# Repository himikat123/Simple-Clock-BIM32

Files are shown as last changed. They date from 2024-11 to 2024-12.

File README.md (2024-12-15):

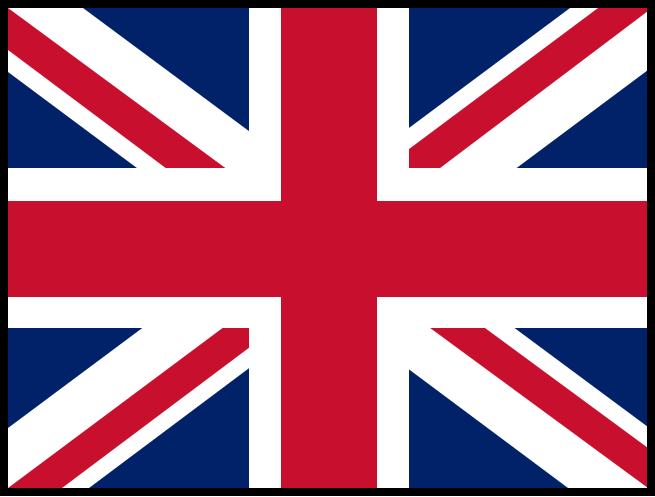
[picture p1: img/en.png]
Read this in english

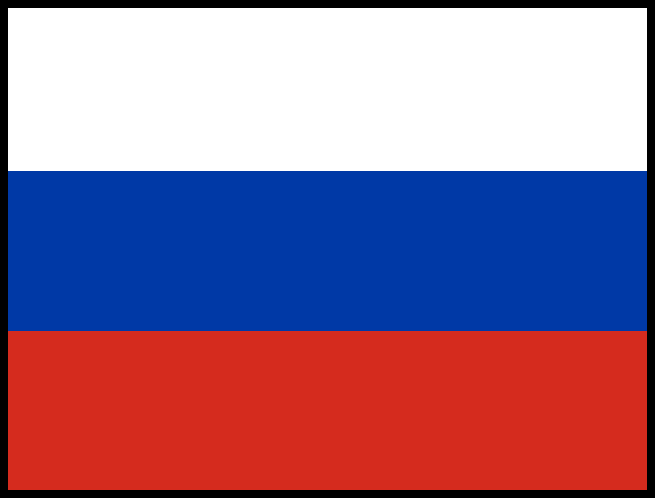
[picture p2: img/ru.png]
Читать на русском
 

# Simple Clock BIM32
## Clock based on ESP32 and TM1637 or MAX7219 Display

<p align="center">simple clock bim32</p>

Simple clock, you can connect 1 or 2 identical or different displays. Each display can have 4, 6, or 8 digits. In this article I will show this clock in its simplest version, i.e. ESP32, 1 display (8 digits) and a case. 
I will also talk about the additional features of this clock as well. Thanks to the large number of possibilities and settings, everyone can build a suitable clock for himself, with a set of individual functions.

### Brief list of clock features:

* Display time (hours, minutes, seconds, milliseconds), date, month, and year
* Connects to a 2.4 GHz home WiFi network
* Synchronizes the time with an NTP server
* Displays current weather (temperature/pressure/humidity)
* Displays indoor temperature, humidity, CO2 levels, and air quality
* Controls home climate devices (humidifier, dehumidifier, heater, cooler, air purifier)
* Sends/receives data to/from the Thingspeak service
* Sends data to the narodmon service
* Supports up to 2 wireless temperature/pressure/humidity/CO2/light/voltage/current/power/energy consumption sensors
* Supports wired sensors for temperature/pressure/humidity/light/air quality
* Auto adjusts screen brightness (based on a light sensor, time, or sunrise/sunset)
* Option to connect a second display
* Speaking clock function
* Alarm clock that plays MP3 files
* Sound notification when temperature, humidity, CO2, or air quality exceeds comfort limits
* Highly flexible settings via web interface

## Display Connection Diagram
To start and operate the clock, it is enough to connect the **display** to the **ESP32**. Connecting all other modules is optional.

Instead of conventional schematics, I’ve provided semi-drawings/semi-photos for clarity, even for beginners and non-professionals. Professionals, please don't be upset—proper schematics will be provided too.

You can use a ready-made display on a specialized chip TM1637 (4 or 6 digits), or on MAX7219 (4 to 8 digits). These displays are very common and cheap, it is not difficult to buy one. The diagram below shows how to connect the display. I have shown both supported displays, but only one needs to be connected.

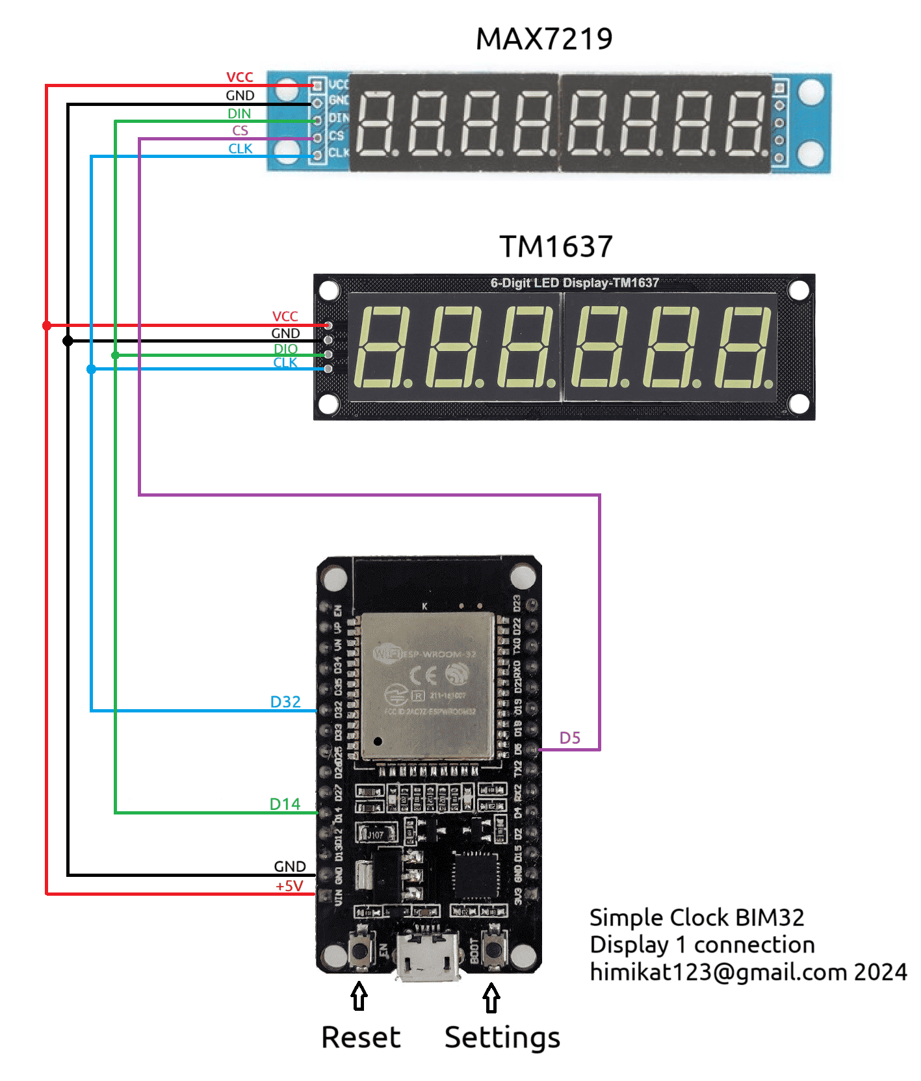
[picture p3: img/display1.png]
simple clock BIM32 display1 wiring diagramm


Additionally, a second display can be connected using the following diagram:

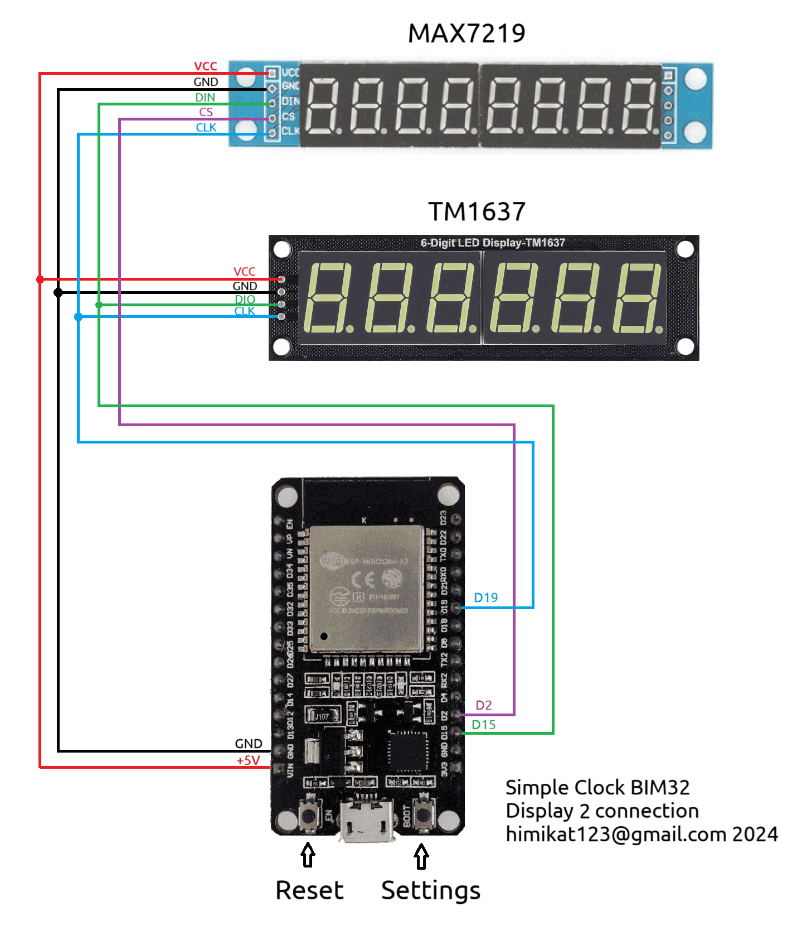
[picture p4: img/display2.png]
simple clock BIM32 display2 wiring diagramm


If you need to have a button (or buttons) handy to turn the display(s) on/off, they can be connected as shown in the diagram.

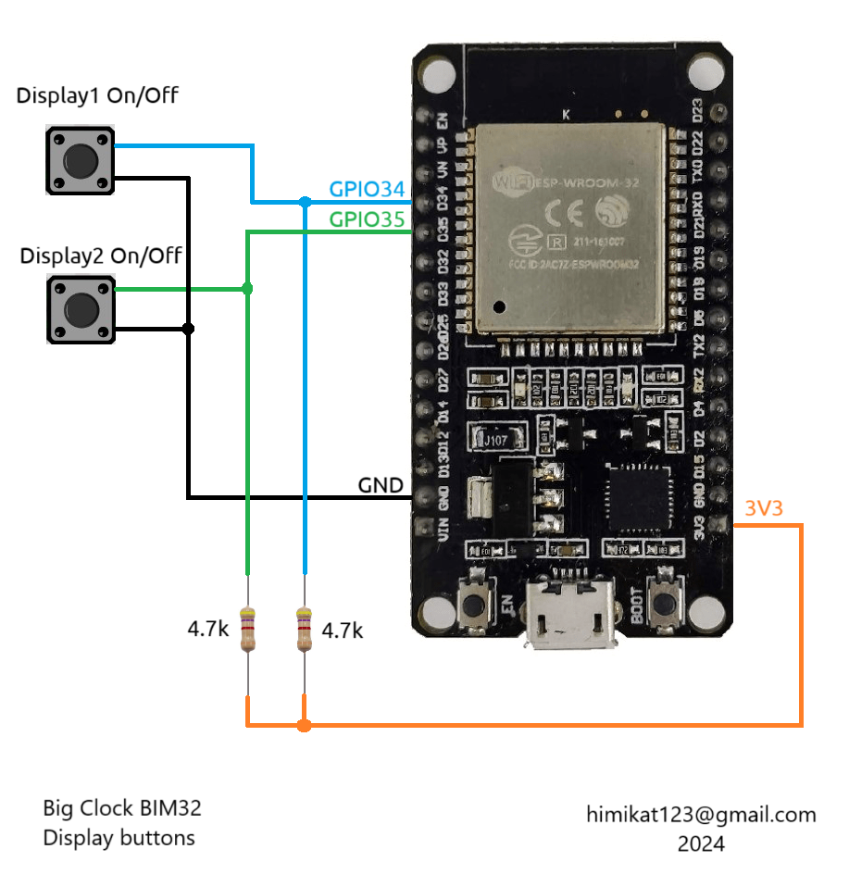
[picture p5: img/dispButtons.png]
simple clock BIM32 display buttons


## Connecting Wired Sensors 
The **clock** can connect to wired sensors for temperature, humidity, pressure, air quality, and light level. Supported sensors include:

* BME280
* BME680
* BMP180
* SHT21
* DHT22
* DS18B20
* MAX44009
* BH1750
* Photoresistor

You can connect one, several, or all of the sensors from this list. It's also recommended to install the DS3231 real-time clock chip, though it is not required. The connection diagram is as follows:

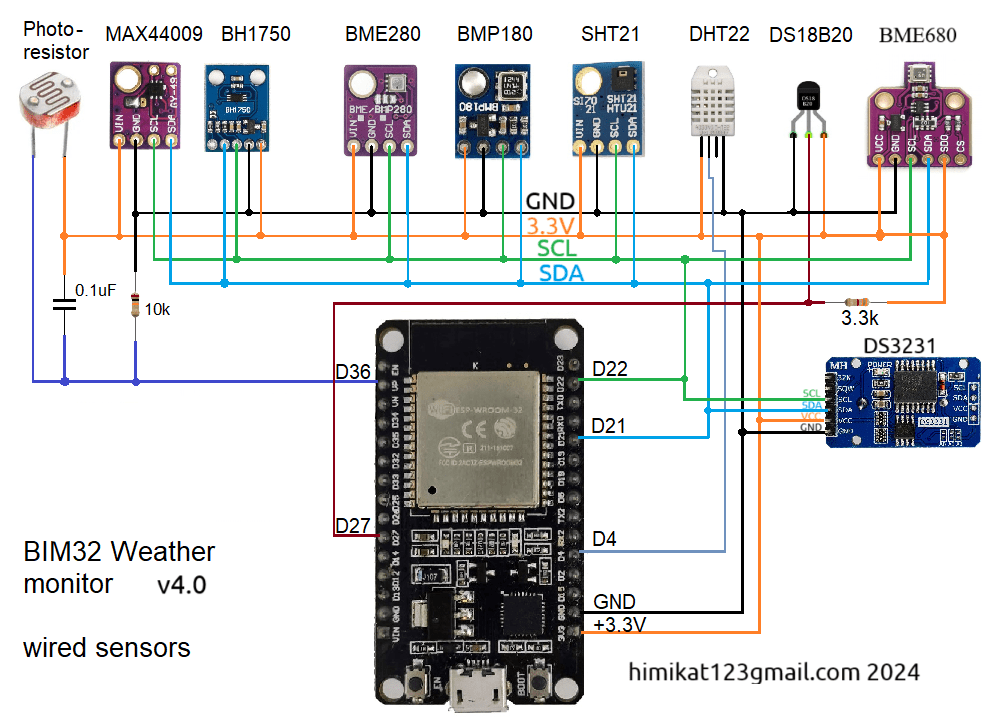
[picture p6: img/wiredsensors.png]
simple clock BIM32 wired sensors


## Wireless Sensor Connection Diagram 
The **clock** can also be connected to **[wireless sensors](https://github.com/himikat123/Radio-sensor)** by adding the **HC-12** radio module, following the diagram below.

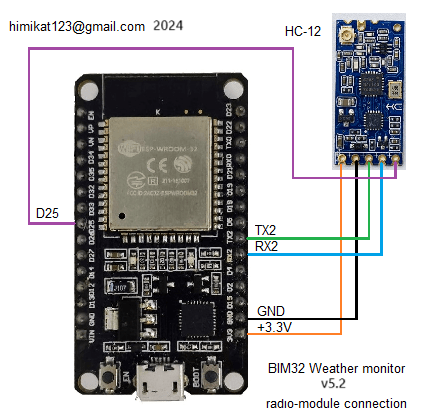
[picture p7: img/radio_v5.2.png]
simple clock BIM32 radio channel


## Home Climate Control Device Connection Diagram 
To control the climate in your home, you can connect a humidifier and dehumidifier, as well as a heater, cooler (fan or air conditioner), and air purifier. I can't provide a connection diagram for these devices because it depends on how the control is implemented in each specific device (remote control, buttons, voltage). However, I will outline on which pins of the **PCF8574** the logic high signals will appear when each device needs to be turned on.

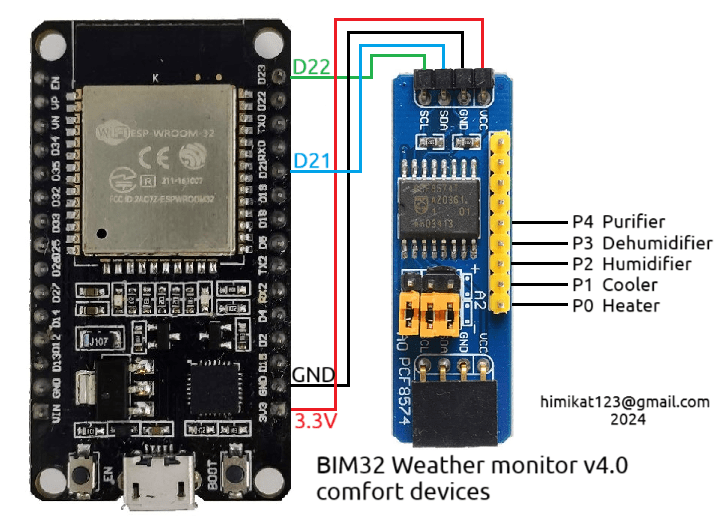
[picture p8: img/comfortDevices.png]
simple clock BIM32 humidifier dehumidifier heater cooler


## Sound Module Connection Diagram 
To enable the alarm and speaking clock sounds, the **DF-Player mini** MP3 player module is used, with the connection diagram provided below. You will need to copy all contents from the **SDcard folder** onto a **micro-SD card**, formatted in **FAT32**. If sound is not required, connect the ESP32's GPIO18 pin to ground.

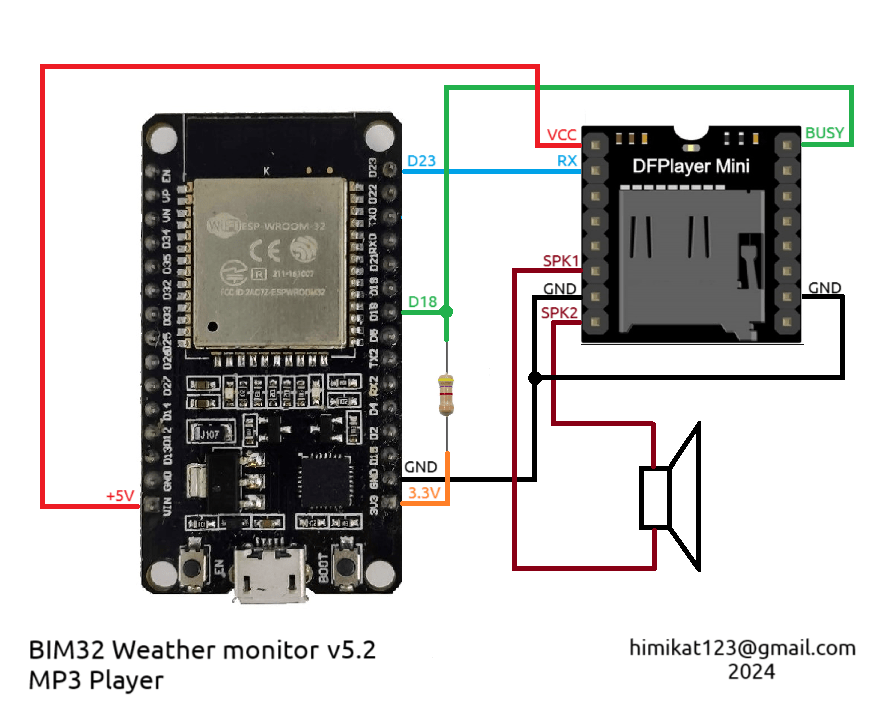
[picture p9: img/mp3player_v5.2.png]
simple clock BIM32 MP3-player


During use, an unpleasant issue with the MP3 player module was discovered: it produces constant low noise. To eliminate the noise, the resistor needs to be resoldered from position A to position B, as shown in the photo below. This switches the MUTE input of the amplifier to the BUSY output, which produces a logic signal only when sound is playing.

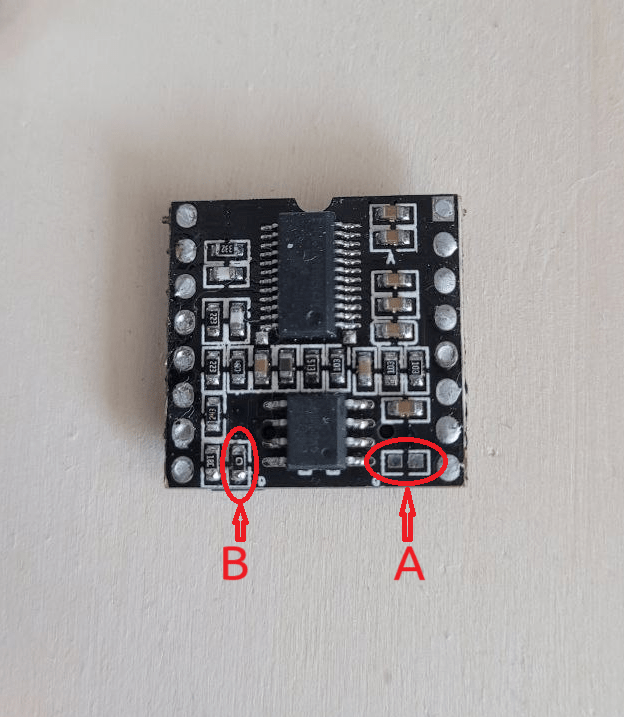
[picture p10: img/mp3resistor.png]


## Clock Schematic

As promised, here's a proper general schematic for general reference. 

```diff
- Please note: if you choose not to install the buttons 
- (to turn the display on/off or disable the alarm), 
- the pull-up resistors for these buttons still need to be installed.
```

The diagram shows all the parts that can make up the clock. But, as I said before, except for the ESP32 module and one of the displays, all other parts do not need to be installed. Light sensor (BH1750, MAX44009 or photoresistor), if you need it, install it in the clock case. But the temperature and humidity sensors should be installed outside the case of the clock, because inside the case the temperature is higher, respectively the humidity is lower. 

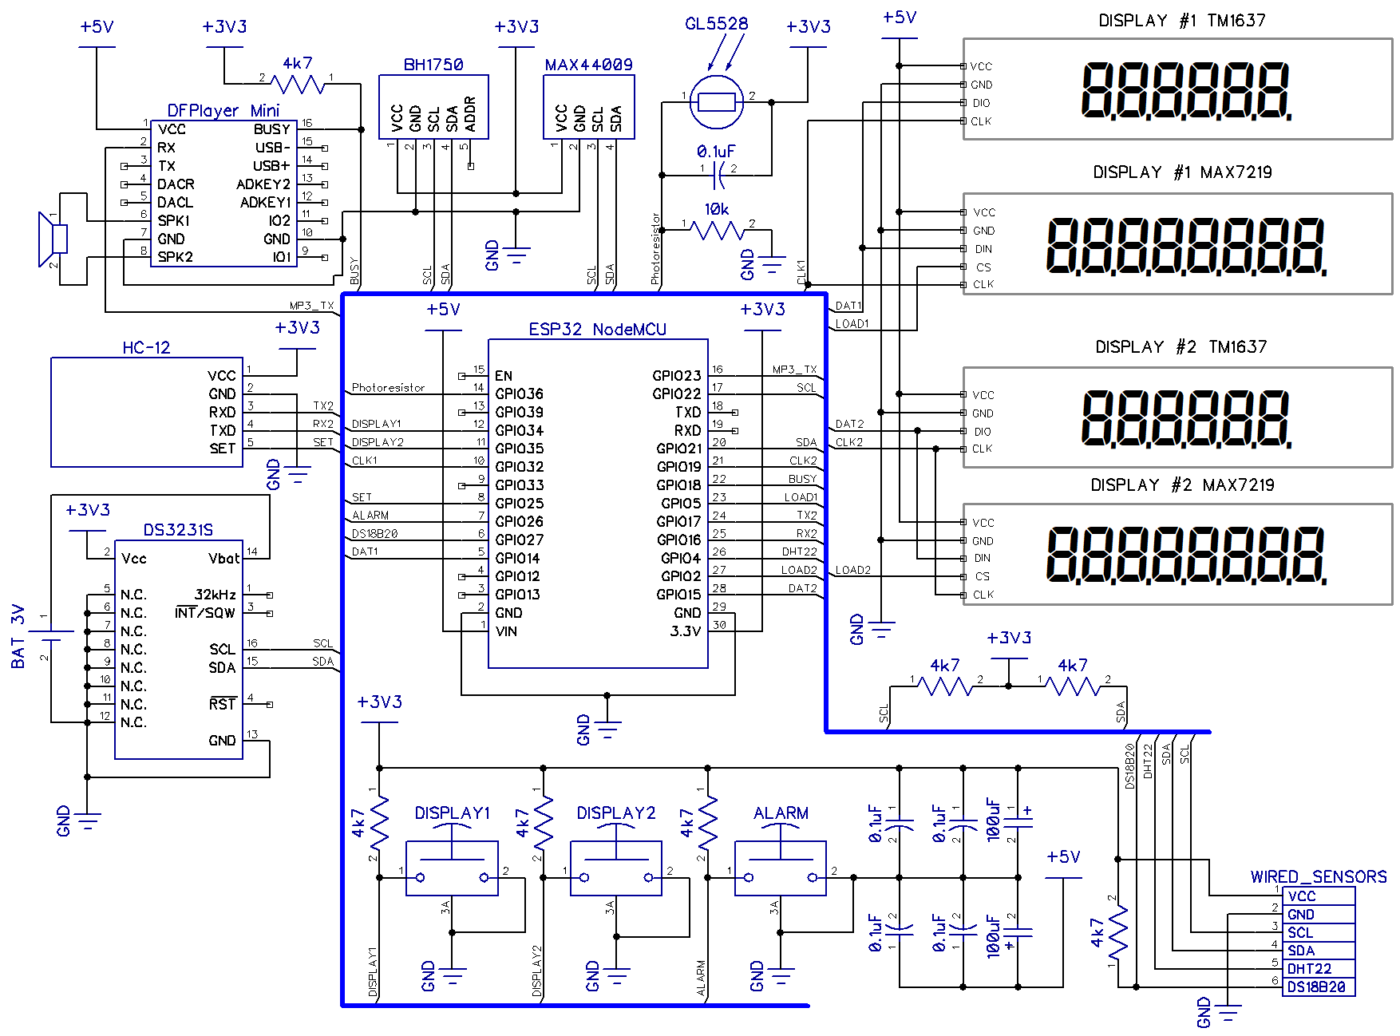
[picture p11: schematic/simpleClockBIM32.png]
simple clock BIM32 schematic diagramm


I didn't make a PCB, I mounted everything by surface mount. Of course, if you need 2 displays and you will use sound module, wired and wireless sensors, buttons, it is better to make a PCB. If someone makes a board, please send me the files and I will add them to the repository.

## Clock Firmware

There is no separate firmware for this clock. The firmware from the [BIM32 weather monitor](https://github.com/himikat123/Weather-monitor-BIM32) is compatible.

To flash the clock firmware, you will need a **micro-USB** cable and a computer:
1. Download [flash_download_tools](https://www.google.ru/search?q=flash_download_tools)
2. Run it and select ESP32 DownloadTool
3. Select the firmware binary files (found in the [bin](https://github.com/himikat123/Weather-monitor-BIM32/tree/master/bin) folder) and addresses as shown in the screenshot, along with the COM port number
4. Press the Start button in the flashing tool and the Settings button on the clock (BOOT button on the ESP32 module). Hold the Settings button until flashing begins.

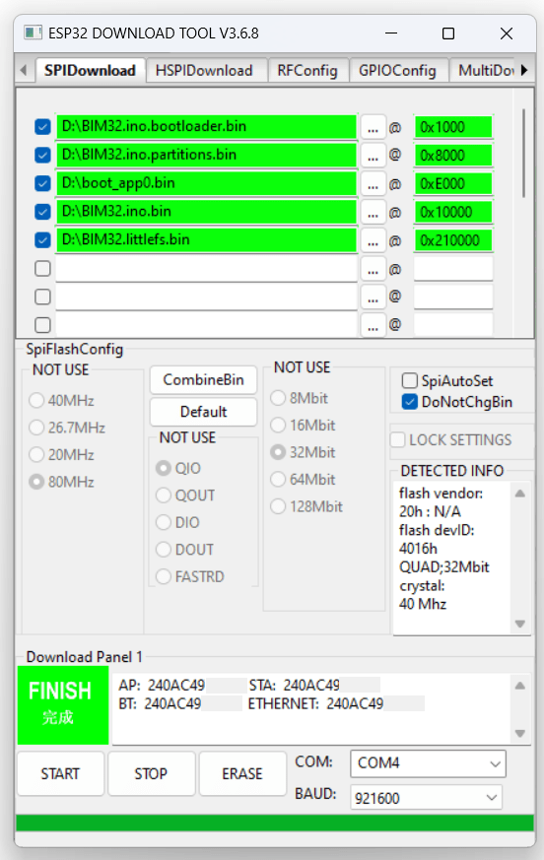
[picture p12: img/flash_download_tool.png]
simple clock BIM32 flashing


After flashing, the **clock** needs to be configured. Unconfigured clock will automatically enable the access point **BIM32** (create a WiFi network) with the default password **1234567890**. Later, to re-enable this network, press and hold the **Settings button** until **"AP"** (short for Access Point) appears on the screen. Connect a laptop or phone to the **BIM32** network, open a browser, and go to **http://192.168.4.1**. Enter the username **"admin"** and the password **"1111"** to access the settings page. It’s recommended to change the default username and password for security purposes.

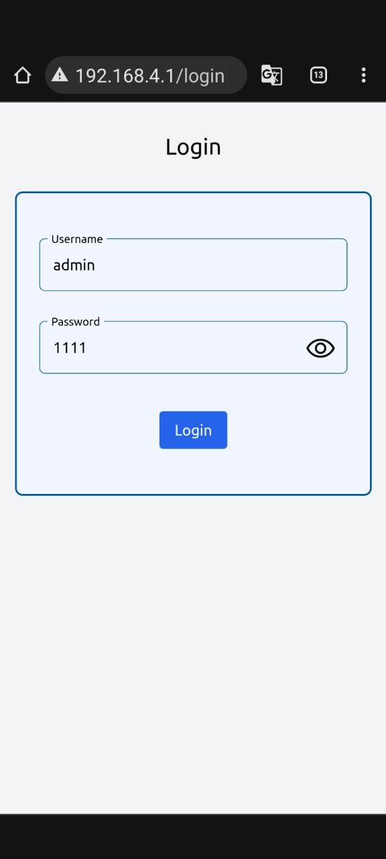
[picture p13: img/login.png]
simple clock BIM32 login


Additionally, once the **clock** is configured and connected to the network, you can access the settings without pressing the Settings button by entering the clock’s **IP address** in a browser. You can find this address in your router or set a static IP in the clock settings.

<hr />

## Settings Demo Page can be viewed <a href="https://himikat123.github.io/Web-Interface-BIM/" target="_blank">here</a>.

## Clock Assembly Photo Instructions 

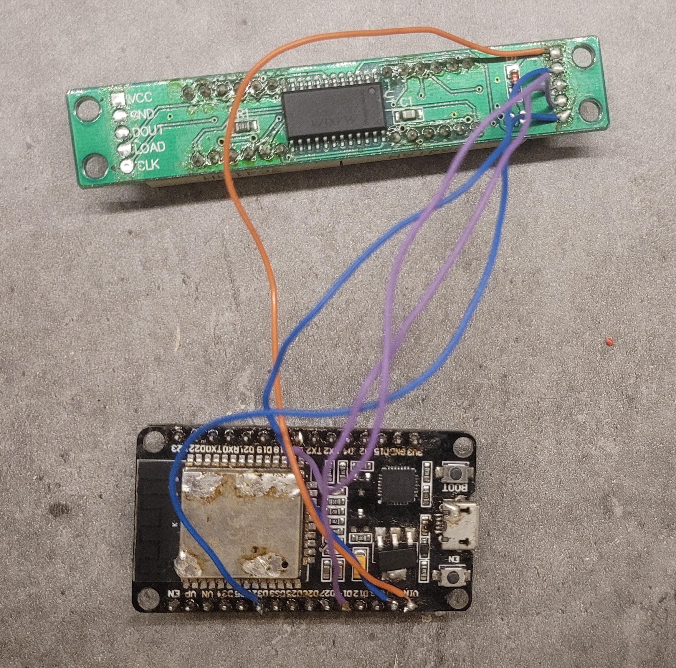
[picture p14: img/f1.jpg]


All three parts of the case (the case itself, the back panel and the buttons) are printed on a 3d printer, you will find the files for 3d printing in the **STL** folder.

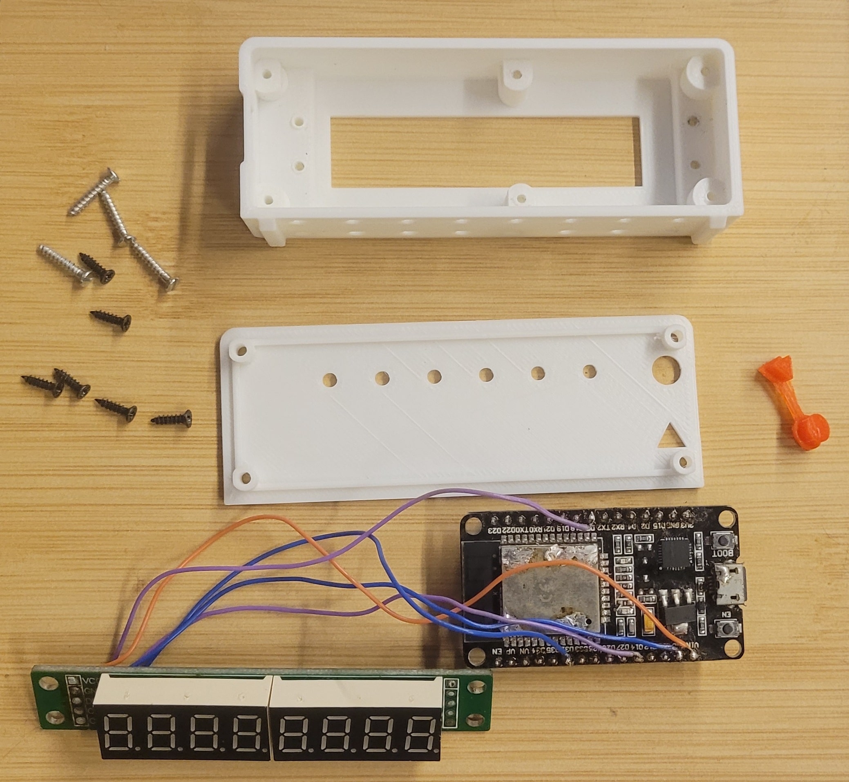
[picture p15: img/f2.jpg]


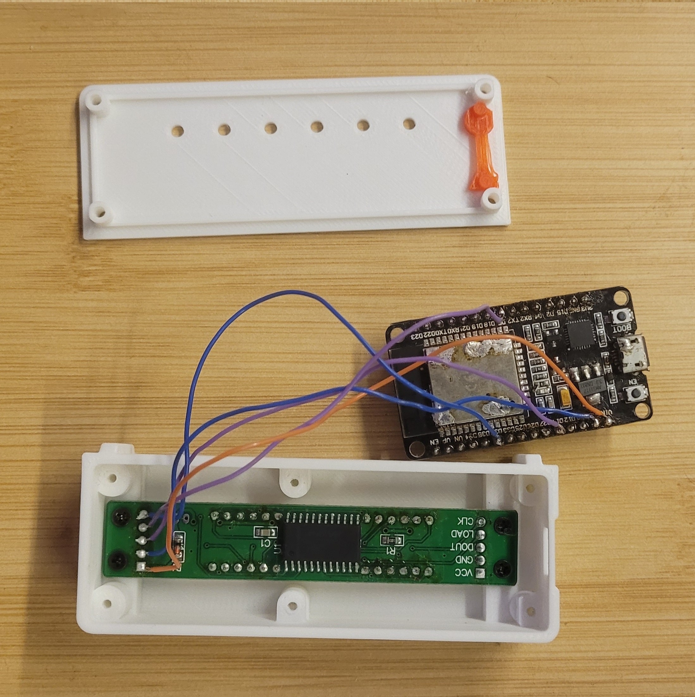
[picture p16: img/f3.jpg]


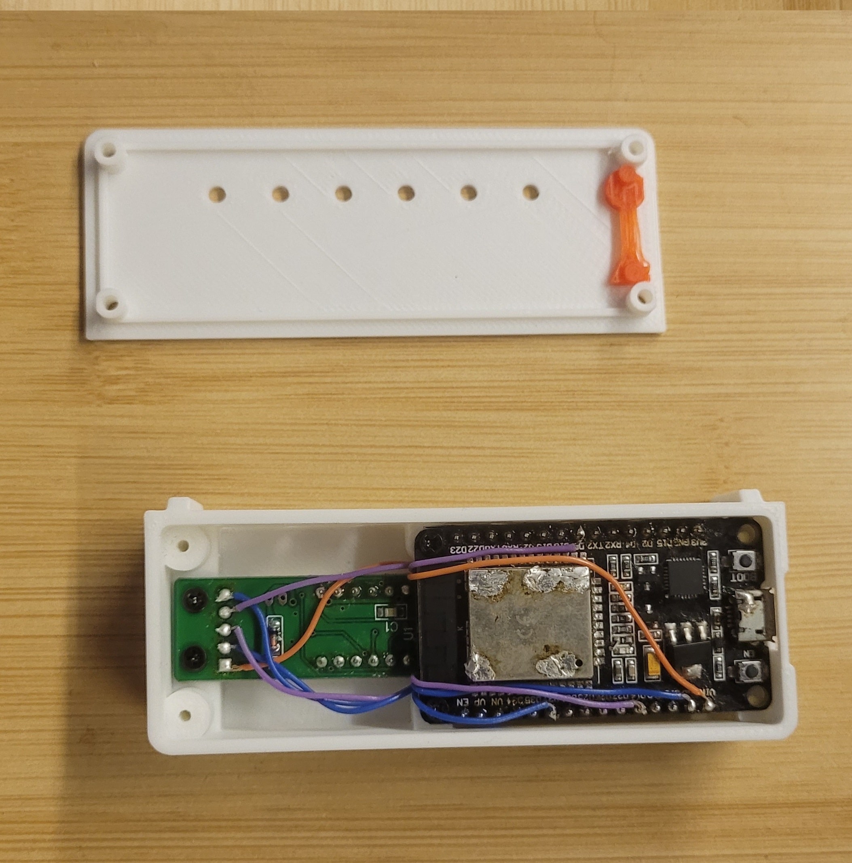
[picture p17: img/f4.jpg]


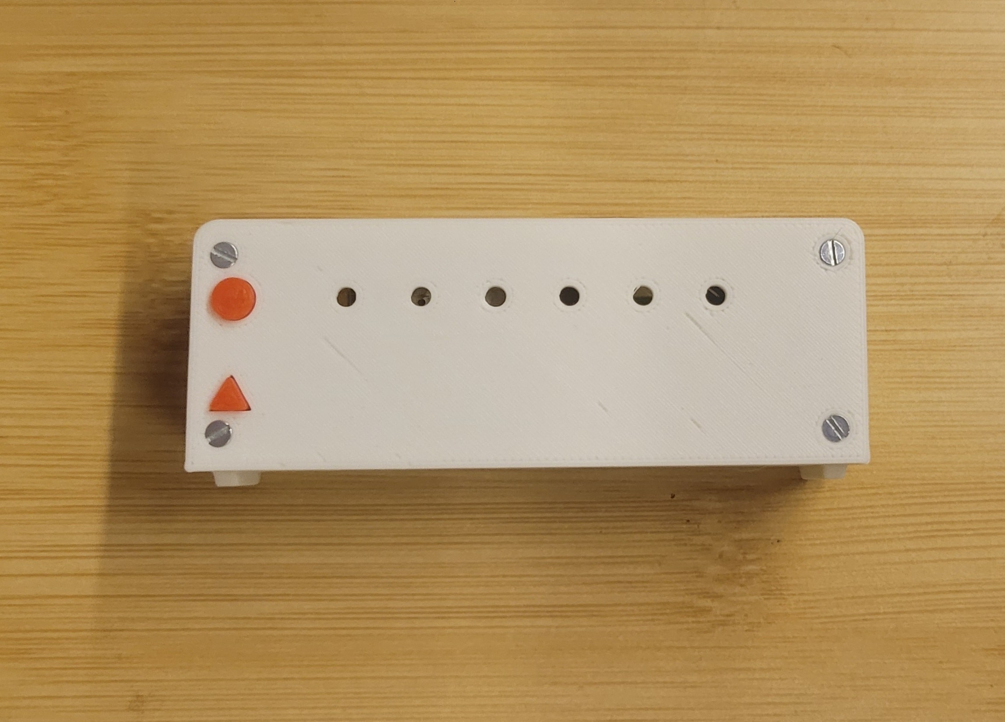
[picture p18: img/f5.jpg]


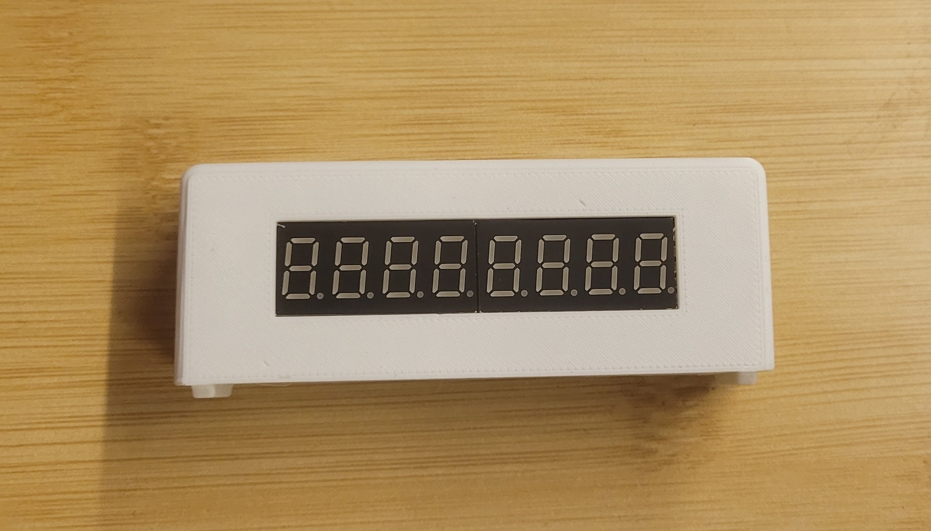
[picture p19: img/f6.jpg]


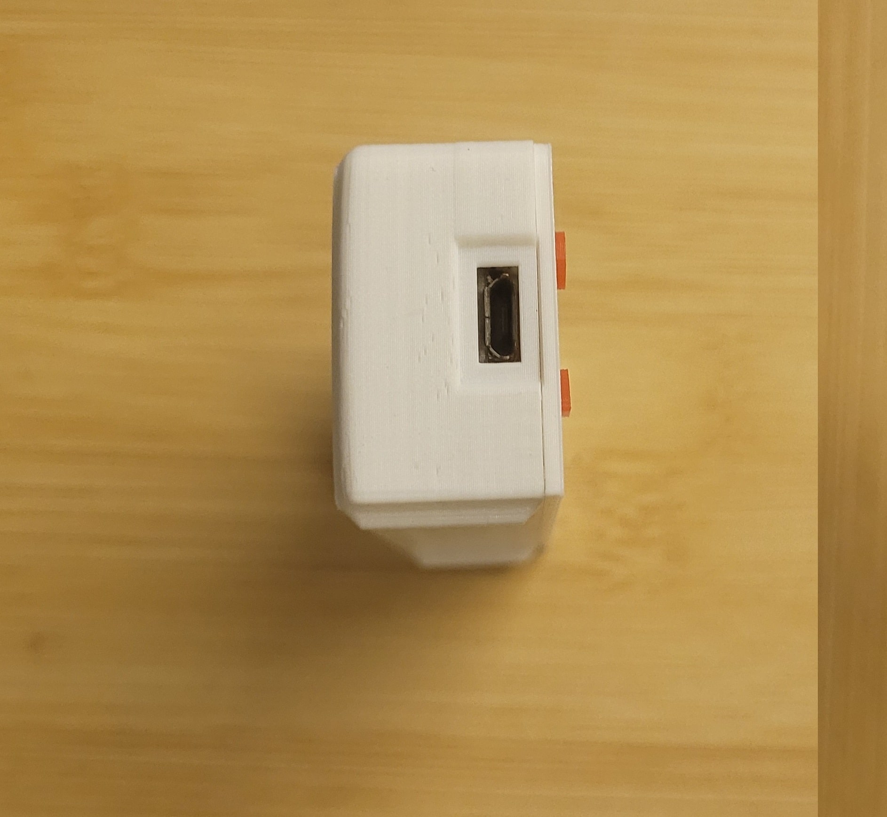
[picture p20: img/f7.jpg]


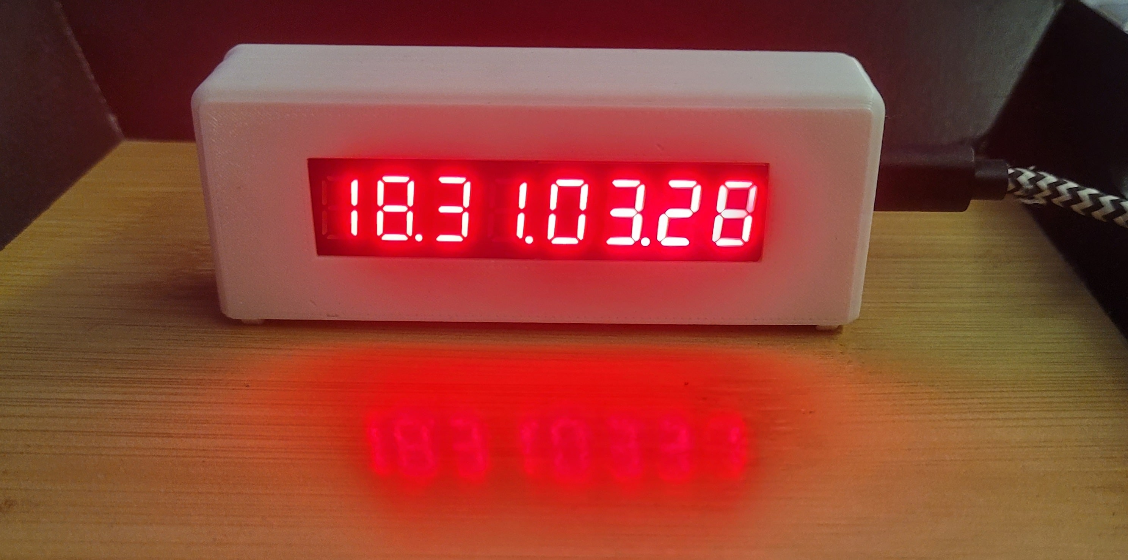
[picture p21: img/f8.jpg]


<hr>

## Do you like the project? Buy me coffee or beer.

<a href="https://www.buymeacoffee.com/himikat123Q">
    Donate
</a>

<a href="https://www.paypal.com/donate/?hosted_button_id=R4QDCRKTC9QA6">
    
</a>

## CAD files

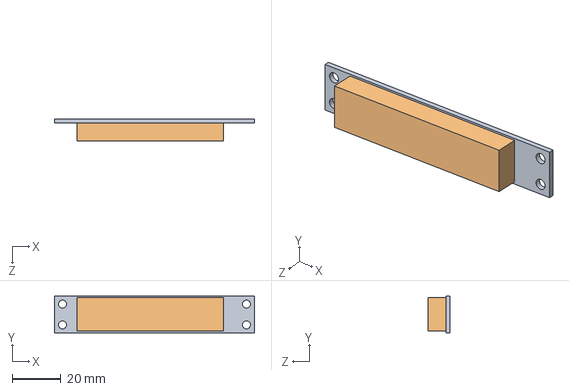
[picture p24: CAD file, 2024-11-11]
Solidworks2023/display 0.36/display.SLDASM
82.4 x 15.2 x 8.90 mm
disp
disp_pcb

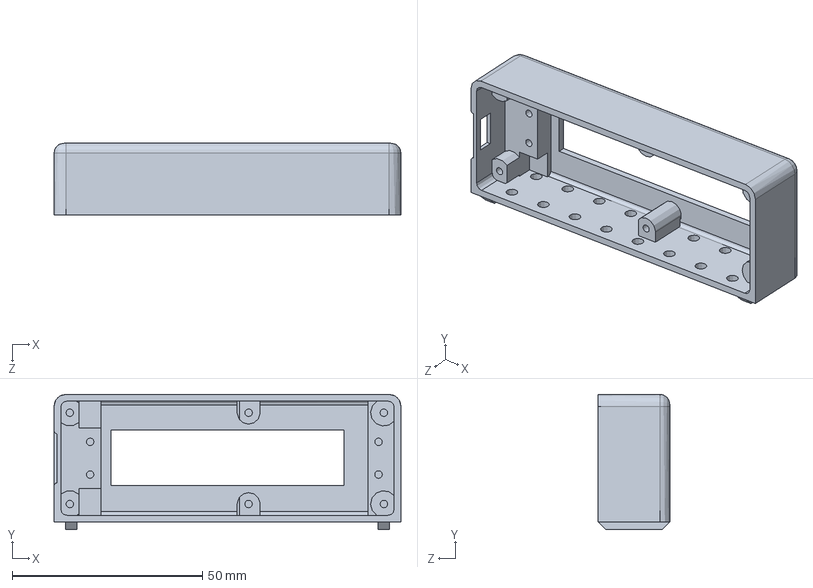
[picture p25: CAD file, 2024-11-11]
Solidworks2023/face.SLDPRT
91.2 x 35.6 x 18.8 mm

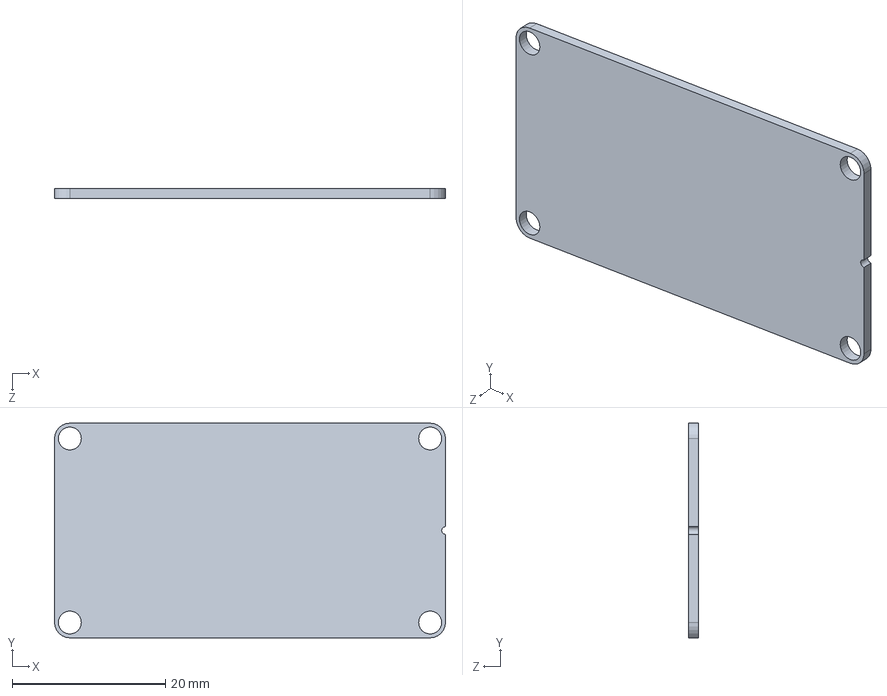
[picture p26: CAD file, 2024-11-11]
Solidworks2023/node mcu/pcb.SLDPRT
51.0 x 28.0 x 1.30 mm

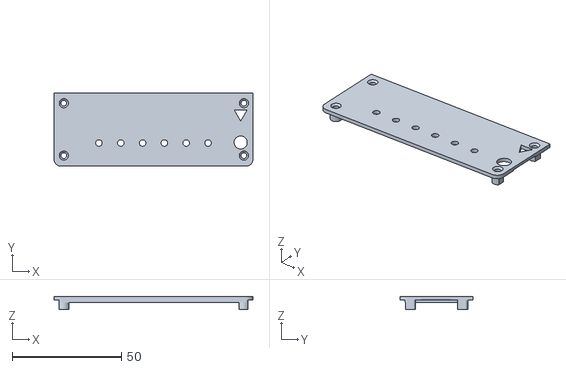
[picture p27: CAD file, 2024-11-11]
STL/cover.STL
91.2 x 33.6 x 6.00

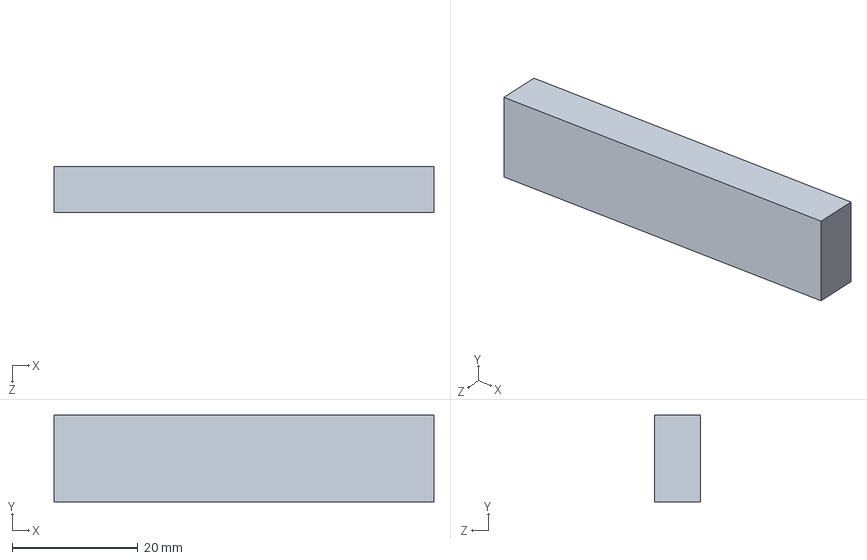
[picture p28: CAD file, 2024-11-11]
Solidworks2023/display 0.36/disp.SLDPRT
60.4 x 13.8 x 7.30 mm

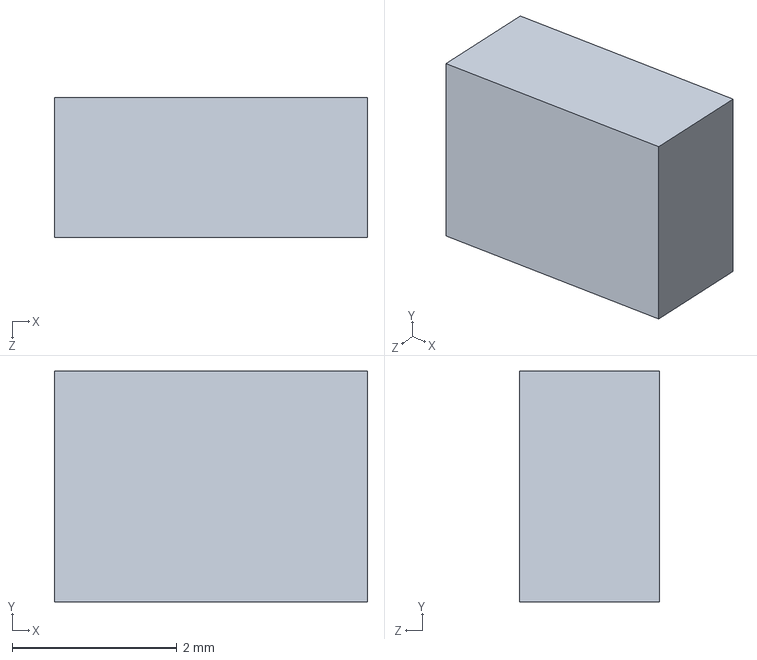
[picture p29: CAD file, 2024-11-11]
Solidworks2023/node mcu/btn1.SLDPRT
3.80 x 2.80 x 1.70 mm

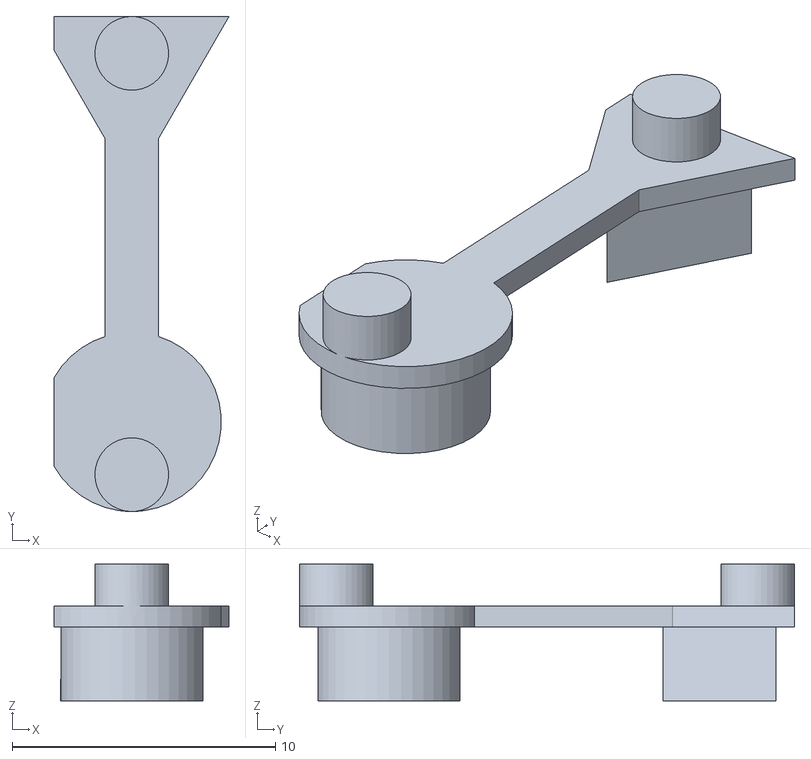
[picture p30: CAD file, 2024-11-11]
STL/buttons.STL
6.65 x 18.8 x 5.20

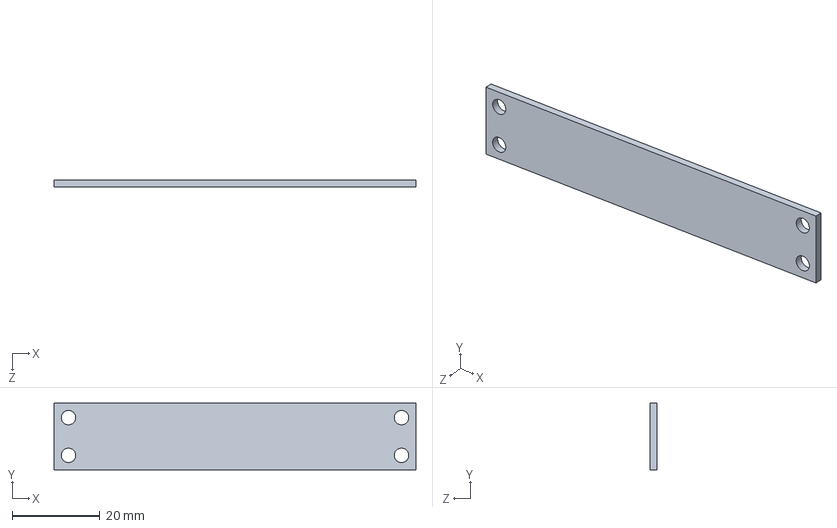
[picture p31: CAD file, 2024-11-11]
Solidworks2023/display 0.36/disp_pcb.SLDPRT
82.4 x 15.2 x 1.60 mm

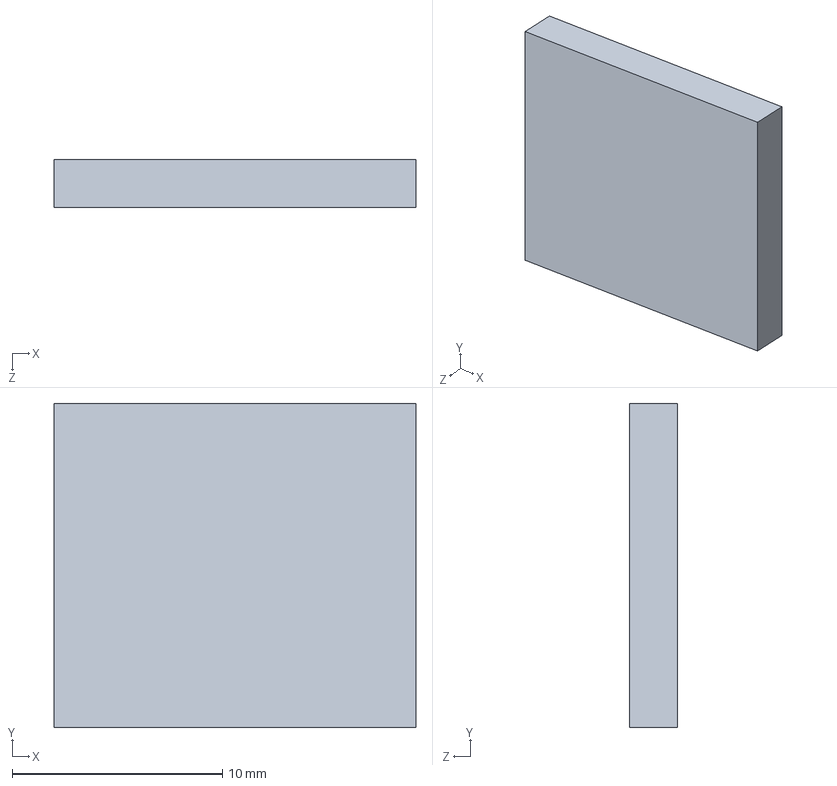
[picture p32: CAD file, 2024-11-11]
Solidworks2023/node mcu/esp2.SLDPRT
17.2 x 15.4 x 2.30 mm

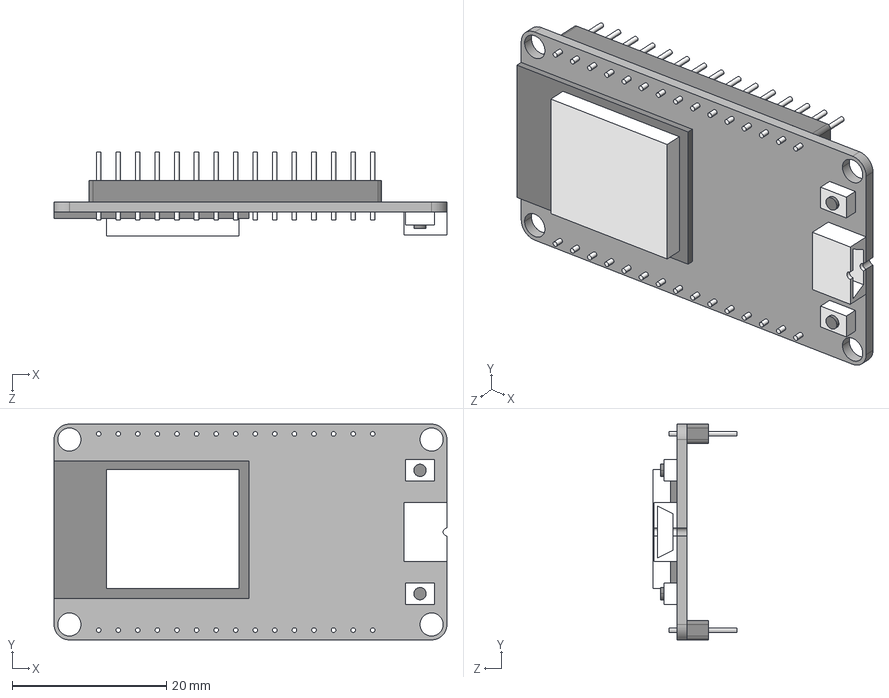
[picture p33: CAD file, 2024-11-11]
Solidworks2023/node mcu/esp32.STEP
51.0 x 28.0 x 10.9 mm
pcb_Standard
esp1_Standard
esp2_Standard
btn1_Standard x 2
btn2_Standard x 2
usb_Standard
dip_Standard x 2
pin_Standard x 2

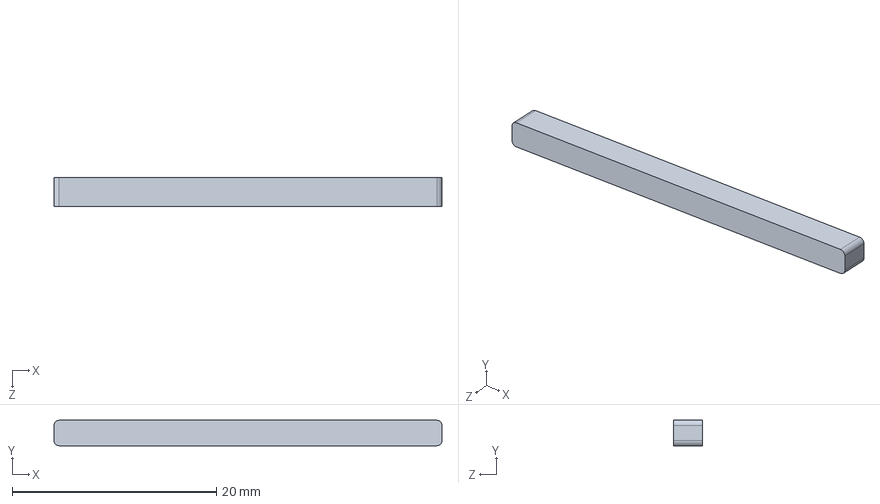
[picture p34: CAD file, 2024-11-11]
Solidworks2023/node mcu/dip.SLDPRT
38.0 x 2.50 x 2.80 mm

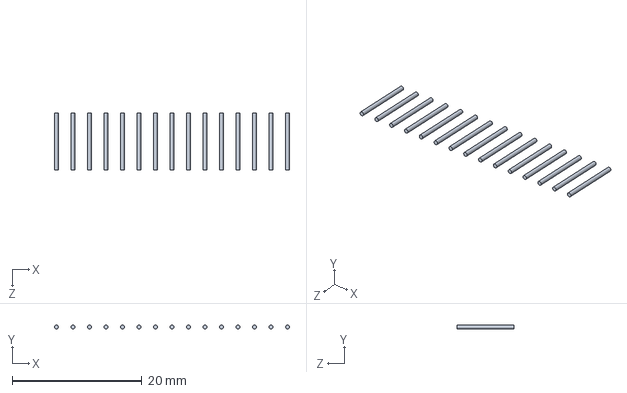
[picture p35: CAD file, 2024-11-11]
Solidworks2023/node mcu/pin.SLDPRT
36.2 x 0.6 x 8.80 mm

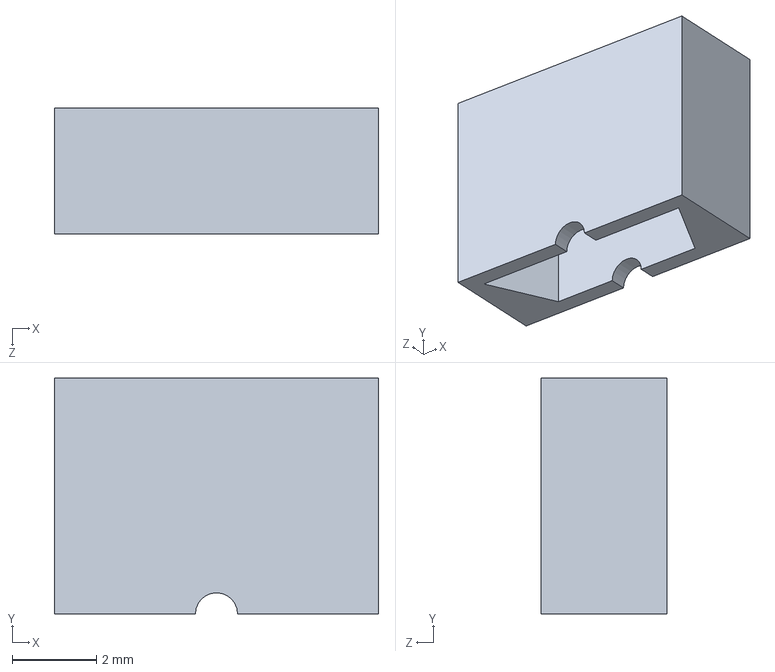
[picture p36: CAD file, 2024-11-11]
Solidworks2023/node mcu/usb.SLDPRT
7.70 x 5.60 x 3.00 mm

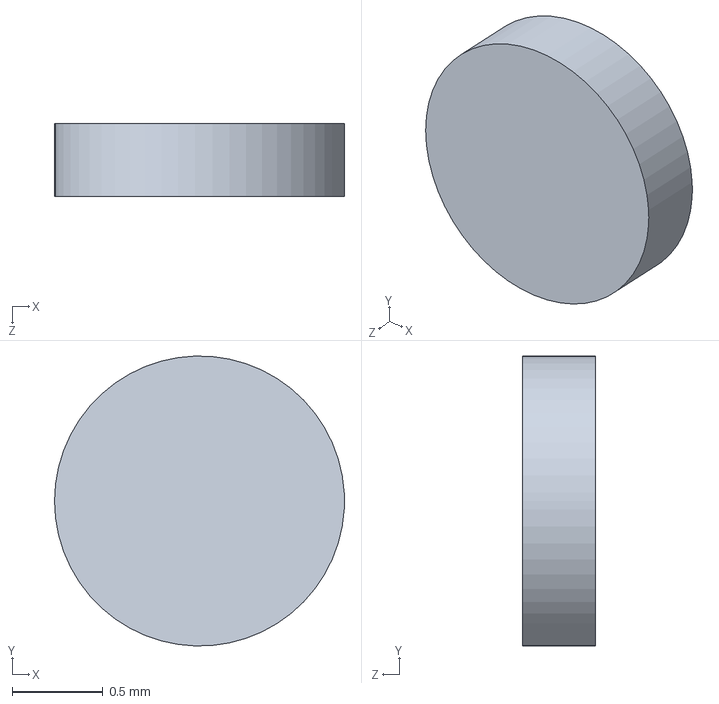
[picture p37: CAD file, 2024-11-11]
Solidworks2023/node mcu/btn2.SLDPRT
1.60 x 1.60 x 0.4 mm

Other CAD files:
Solidworks2023/buttons.SLDPRT
STL/face.STL
Solidworks2023/cover.SLDPRT
Solidworks2023/node mcu/esp1.SLDPRT
Solidworks2023/node mcu/esp32.SLDASM

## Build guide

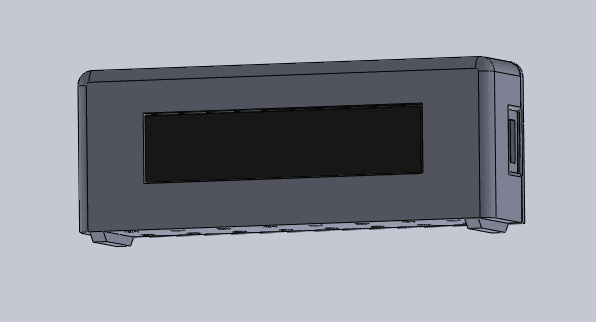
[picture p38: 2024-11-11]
Solidworks2023/assembly.png

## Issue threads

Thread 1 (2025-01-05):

Missed bin files

apimentebr, 2025-01-05:
I can't find the bin files. Are they missed?

apimentebr, 2025-01-05:
I loaded these files, but I can't find the display TM 1637 in the web menu

himikat123, 2025-01-05:
It is here

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

apimentebr, 2025-01-05:
When I choose "7 segment" only a blank page is show. I've tested with 2 different ESP32 in the PC and in the cellphone

himikat123, 2025-01-06:
There is such a problem when flashing binaries. I am already working on a fix

himikat123, 2025-01-06:
Fixed. Download the binaries again.

Closed 2025-01-07.

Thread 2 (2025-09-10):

Вопрос по работе DS3231

evgaleta, 2025-09-10:
Привет! Собрал простые часы на ESP32. Очень благодарен, хороший проект для изучения ESP. В схеме сейчас такие элементы: ESP32-Wroom-32, индикатор MAX7219, BMP180, модуль часов от RaspberryPi, DFPlayer mini. На данный момент версия прошивки 5.6b, версия интерфейса 3.0.
Все работает, хотя не обошлось без плясок с бубном вокруг config.json.
Сейчас осталась одна проблема: часы почему-то каждый раз после перезагрузки показывают время с отставанием на 15-20 секунд и, иногда, не отрабатывают переход на летнее время просто в процессе работы (показывают на час меньше летнего времени).
Выглядит это так: синхронизирую время с NTP или компьютером, сохраняю - все точно, идут. Перезагружаю через WEB-интерфейс, сначала на индикаторе 0-00, потом дата 01.01.70, потом после опроса датчика у меня опять время с секундами - сначала точное, потом видна коррекция на отставание на те самые 15 секунд. Дальше все работает. Модуль часов проверен в RaspberryPi и работает, батарейка в нем тоже в норме. Куда смотреть, не подскажете?

himikat123, 2025-09-10:
Привет! Спасибо, не замечал таких глюков, обязательно все перепроверю и исправлю то что найду

evgaleta, 2025-09-10:
Я еще не могу понять одного: синхронизация с NTP включена, интернет есть, но коррекция этой ошибки не происходит. Или при установленных часах нужно отключать коррекцию?

himikat123, 2025-09-10:
Нет, коррекцию отвключать не нужно, но она и не работает постоянно, лишь раз в 15 минут, или как вы ее настроите. Но вот, похоже, что именно коррекция по NTP и уводит время на 15-20 секунд. Нужно разобраться почему

evgaleta, 2025-09-15:
Спасибо, с нетерпением жду новой версии! Наш девиз: превратим все баги в фичи!

Кстати, в бета-версии проблемы с выключением будильника нет, но кнопка срабатывает на второе нажатие. Тоже можно фичей назвать, типа, осознанное отключение, нажми два раза...

burakovlesa75-ship-it, 2025-09-19:
Простите, может не по теме, у меня ESP32 CH9102F лилиго т дисплэй, кто-то подскажет где тут найти нужную прошивку марадёр, просто я тут новенький, еле и везде все по английски, помогите плиз, как скопировать код и залить в есп то знаю, а где его тут найти?

himikat123, 2025-09-20:
Прошивки для CH9102F здесь совсем нет, эта тема про часы на дисплее MAX7219 или TM1637. И кстати, на русском тоже есть описание https://github.com/himikat123/Simple-Clock-BIM32/blob/main/README_RU.md

evgaleta, 2025-09-24:
Благодарю за ответ! Буду с нетерпением ждать нового релиза. По поводу хода часов заметил: при входе в web-интерфейс на страницу ЧАСЫ происходит тот самый откат на несколько секунд назад произвольно (5-20 сек). Заметил так: установил время с секундами на постоянное отображение и просто увидел, как показания 10:17:23 поменялись на 10:17:11 и пошли дальше. И так каждый раз. Если сделать синхронизацию с NTP, то до перезапуска или входа в web-интерфейс часы идут изумительно точно. Может это поможет найти причину?

evgaleta, 2025-09-24:
Забыл написать, что часы в web-интерфейсе на первой странице идут АБСОЛЮТНО ТОЧНО, а показания реального  индикатора то отстает, то, после синхронизации, становится точно, но потом опять отстают.

himikat123, 2025-09-24:
Тут я схитрил, признаюсь, на первой странице секунды берутся с вашего браузера. Дело в том, что веб-интерфейс получает данные с ESP32 раз в 5 секунд, поэтому, чтоб секунды на первой странице не стояли и не двигались рывками по 5 секунд, было принято решение сделать чтоб секунды подставлял сам браузер

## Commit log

2024-11-15 file renaming schematic diagram preview
2024-12-15 corrected the schematic-pictures
